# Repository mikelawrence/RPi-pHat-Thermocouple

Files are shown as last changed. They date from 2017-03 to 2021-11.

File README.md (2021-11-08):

# Raspberry Pi Thermocouple pHat

The Raspberry Pi Zero sized Hats are now officially called **Micro-Hats** or **uHats** but for consistency sake, this board's name will remain Raspberry Pi Thermocouple **pHat**.

This is a Raspberry Pi Micro-Hat PCB that supports:

* Three MAX31850 1-Wire Thermocouple Converters for remote temperature sensing
* DS18S20 1-Wire Thermometer for local Hat temperature
* Magnetic Buzzer/Alert

I keep an upright freezer in my garage and on two occasions I have had the freezer die without getting noticed for several days. This project is an attempt to solve my lack of constant oversight. MQTT is used to communicate with Home Assistant home automation software. The MQTT client/server model is very effective in this situation. Home Assistant will monitor the temperature and provide me with alerts so I can do something about the problem before all the food spoils.

## Status

* Rev 2.0 PCB has been ordered from OSH Park and has been fully tested.
  * Removed one of the four MAX31850K's.
  * Increased thermocouple input filtering by adding ferrite beads and a larger capacitor.
  * Added DC Power connector and switching power supply that powers both the Raspberry Pi and the Hat.
  * The occasional noisy reading from the MAX31850K's are reduced in this version but not gone.
  * You can order parts from Mouser using this [shared BOM](https://www.mouser.com/ProjectManager/ProjectDetail.aspx?AccessID=bd69c35967).
  * You can order the PCB from OSH Park using this [link](https://oshpark.com/shared_projects/meYar6Ji).
* Rev 1.2 PCB has been ordered from OSH Park and tested.
  * Discovered the MAX31850K's get a noisy reading about 0.1% of the time. This noise is typically within 5 C but sometimes is greater than 30 C. Adding capacitors did little to help the Rev 1.1 design so most of the 3.3V power was switched to a 3.3V LDO regulator in an attempt to reduce the noise on the 3.3V power seen by the MAX31850K's.
  * You can order parts from Mouser using this [shared BOM](http://www.mouser.com/ProjectManager/ProjectDetail.aspx?AccessID=7612d46eeb).
  * You can order the PCB from OSH Park using this [link](https://oshpark.com/shared_projects/S5a4ZDvw).
* Rev 1.1 PCB was never built.
  * Added a pulldown on the alert signal to prevent the Alert buzzer from sounding on power on.
  * Added an on board DS18S20.
* Rev 1.0 PCB has been ordered from OSH Park and tested.
  * Discovered the linux kernel doesn't seem to support MAX31850K devices without a DS18S20 present. The kernel detects the MAX31850K devices but does not create a w1_slave file to read the temperature. This is most likely a bug in the Linux W1 driver.

## Board Preview

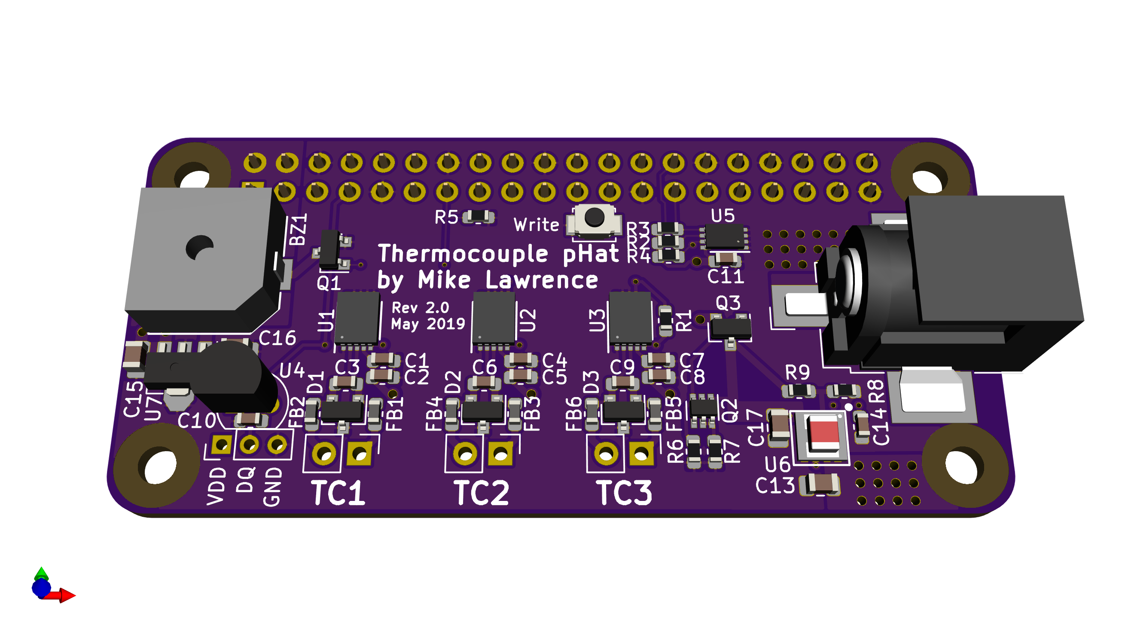
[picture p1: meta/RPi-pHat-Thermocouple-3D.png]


## Kicad Notes

* This PCB design uses my custom libraries available here [Mike's KiCad Libraries](https://github.com/mikelawrence/KiCad-Libraries).
* This PCB design is based on [RPi_Zero_pHat_Template](https://github.com/mikelawrence/RPi_Zero_pHat_Template).
* This PCB was designed with [KiCad 5.1.2](http://kicad.org).
* For Bill of Materials generation I use my version of [KiBoM](https://github.com/mikelawrence/KiBoM) forked from [SchrodingersGat](https://github.com/SchrodingersGat/KiBoM).
* The LMZ21700 Simple Switcher, AT24CS32, and MAX31850K parts have an exposed pad on the bottom which requires either a reflow oven or hot air to solder properly.

## Design

### Input Power

This Hat will safely power the Raspberry Pi and this board up to 650mA. Keep in mind that 650mA is not enough for the minimum specified backpower of 1.3A. It is however enough to power (with room to spare) a Raspberry Pi Zero W with nothing else connected. The Barrel Jack will accept 6-11VAC or 6-17VDC. This input voltage is rectified and filtered and applied to a 5VDC Simpler Switcher module from Texas Instruments (LMZ21700). The output of this switcher is applied to the Raspberry Pi 5V through an ideal diode circuit which will prevent any problems when both the Hat and Raspberry Pi are powered simultaneously.

### MAX31850K Thermocouple-to-Digital Converter

Although the MAX38150K datasheet typical application circuit doesn't show the use of ferrite beads many designs seem to include them. That in combination with the larger than normal capacitor across the input will hopefully improve sampling errors even further.

## Raspberry Pi Setup

This setup makes several assumptions. First you are using Raspbian Buster. This software and instructions most likely work on other versions of Raspbian but they have not been tested. Second Python3 is the target programming environment. It is also assumed that you are using the standard `pi` user. Otherwise you will have to edit the commands by replacing `/home/pi` with your user's home directory. Install everything needed by executing the following commands.

```text
sudo apt update
sudo apt -y install git python3-rpi.gpio python3-w1thermsensor python3-paho-mqtt
```

### Get the repository from Github

Clone this repository from Github with the following commands.

```text
cd /home/pi
git clone https://github.com/mikelawrence/RPi-pHat-Thermocouple
```

### Configure ID EEPROM

Raspberry Pi Hats require an ID EEPROM with data that uniquely identifies every hat ever made. Build the EEPROM tools, and make the `eeprom_settings.eep` file.

```text
cd /home/pi/RPi-pHat-Thermocouple/eeprom/
make all
./eepmake eeprom_settings.txt eeprom_settings.eep
```

The next command writes the freshly generated and unique `eeprom_settings.eep` file to the EEPROM but you must push and hold the write switch on the hat before executing this command. By default the EEPROM on the hat is write protected. Pushing the write switch allows writes to occur while the switch is pushed.

```text
chmod 755 eepflash.sh
sudo ./eepflash.sh -w -f=eeprom_settings.eep -t=24c32
```

You will see the following if writing to the EEPROM was successful.

```text
This will attempt to talk to an EEPROM at i2c address 0x50. Make sure there is an EEPROM at this address.
This script comes with ABSOLUTELY no warranty. Continue only if you know what you are doing.
Do you wish to continue? (yes/no): yes
Writing...
0+1 records in
0+1 records out
117 bytes (117 B) copied, 2.31931 s, 0.1 kB/s
Done.
```

This is what you will see if there is a problem communicating with the EEPROM.

```text
This will attempt to talk to an EEPROM at i2c address 0x50. Make sure there is an EEPROM at this address.
This script comes with ABSOLUTELY no warranty. Continue only if you know what you are doing.
Do you wish to continue? (yes/no): yes
Writing...
dd: error writing ‘/sys/class/i2c-adapter/i2c-3/3-0050/eeprom’: Connection timed out
0+1 records in
0+0 records out
0 bytes (0 B) copied, 0.0539977 s, 0.0 kB/s
Error doing I/O operation.
```

If you successfully wrote the EEPROM there is nothing else left to do here.

### Setup Interfaces

For this Hat you will need to enable the 1-Wire interface. From the command line type
`sudo raspi-config` and follow the prompts to install  support in the kernel.

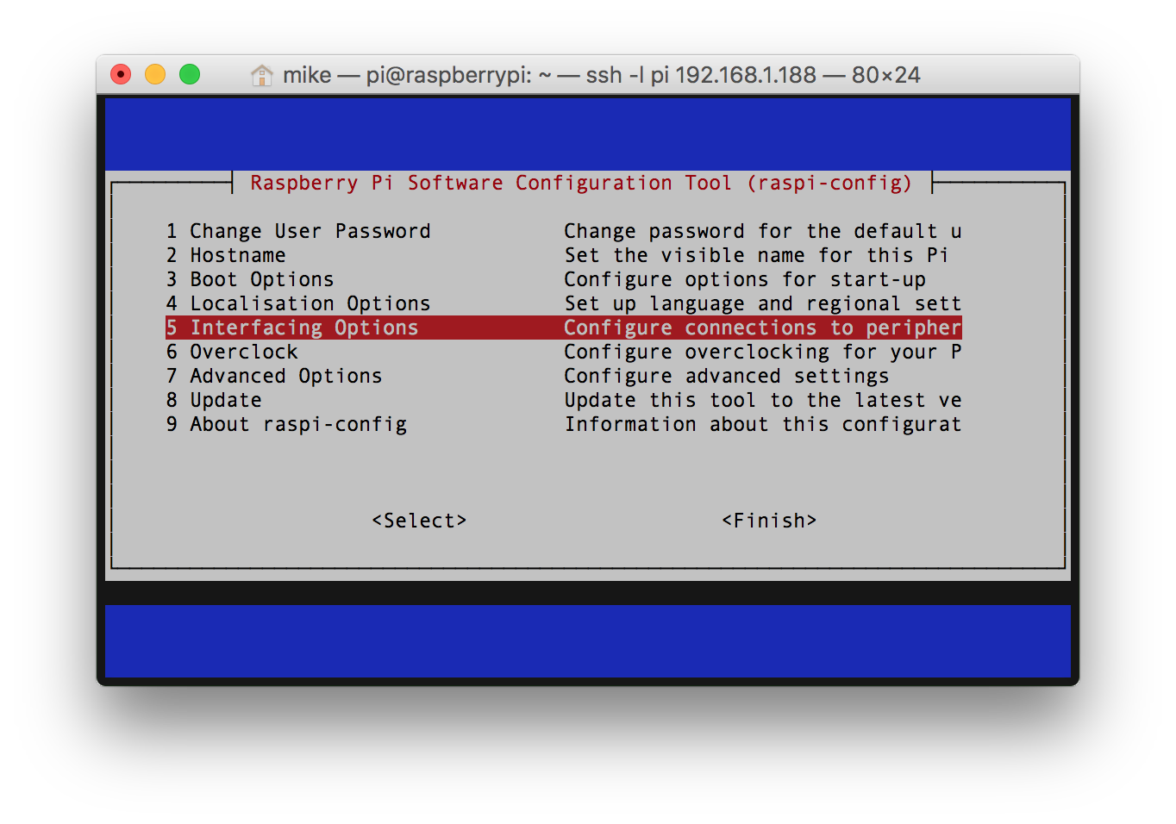
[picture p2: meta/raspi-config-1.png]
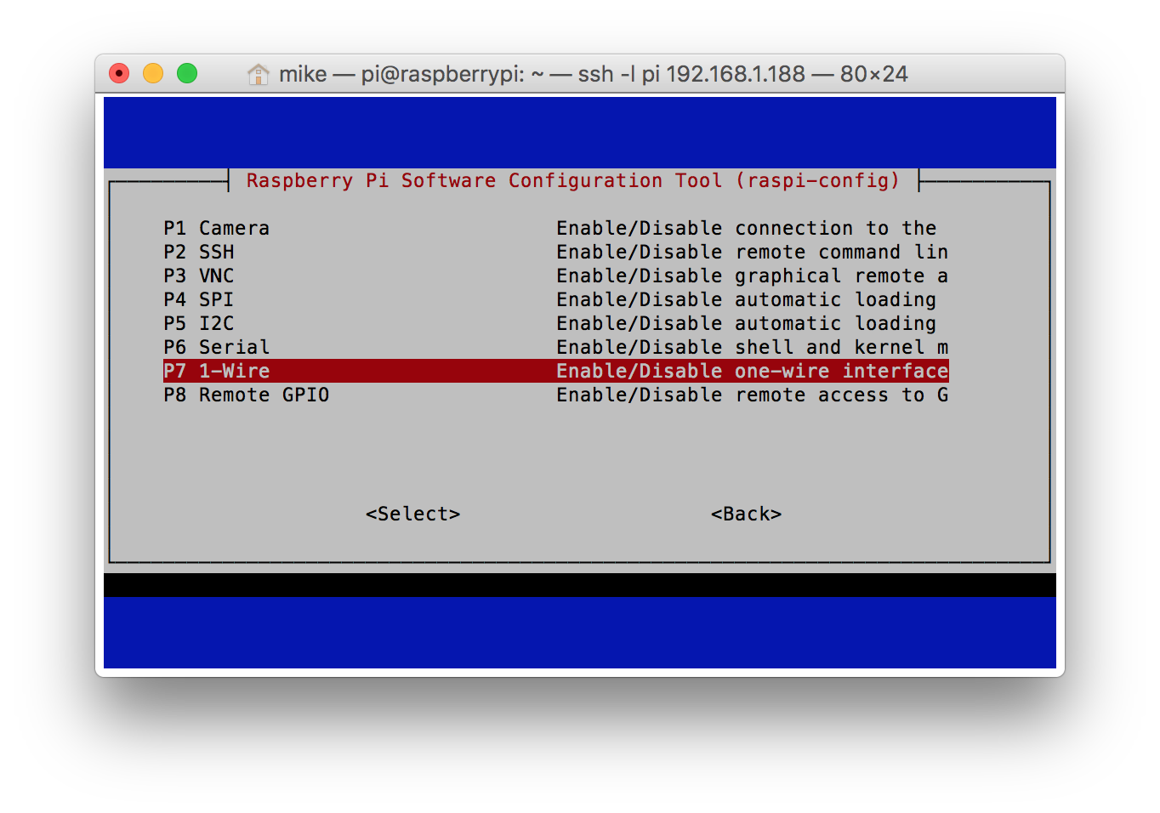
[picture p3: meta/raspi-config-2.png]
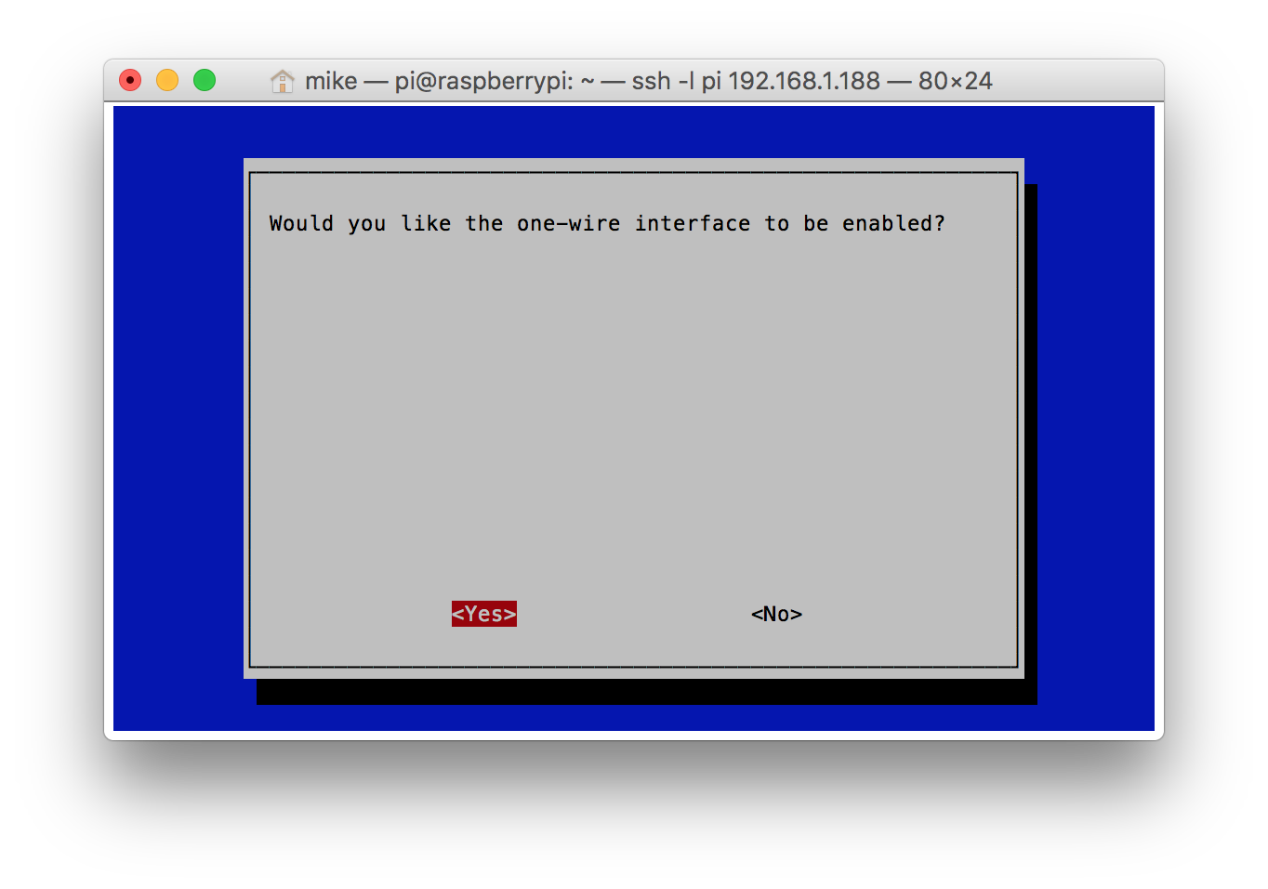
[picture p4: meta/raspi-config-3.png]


It's time to reboot your Raspberry Pi with `sudo reboot`.

### Test the 1-Wire Temperature Sensors

[Python3-w1thermsensor](https://github.com/timofurrer/w1thermsensor) is a nice 1-Wire python library that also supports command line reading of temperatures from 1-Wire devices. You should have already installed this package in the [Raspberry Pi Setup](#Raspberry-Pi-Setup) section.

Test the single on-board DS18B20 temperature sensor using `w1thermsensor all --type DS18S20`.

```text
pi@studio-fridge:~ $ w1thermsensor all --type DS18S20
Got temperatures of 1 sensors:
  Sensor 1 (00080372f2c4) measured temperature: 28.06 celsius
```

Now test the three MAX38150Ks temperature sensor by using `w1thermsensor all --type MAX31850K`.

```text
pi@studio-fridge:~ $ w1thermsensor all --type MAX31850K
Got temperatures of 3 sensors:
  Sensor 1 (000000181928) measured temperature: 23.75 celsius
  Sensor 2 (00000018192b) measured temperature: 24.0 celsius
  Sensor 3 (000000181d59) measured temperature: 2047.81 celsius
```

The 2047.81 celsius reading is what you get when there is no thermocouple connected to the MAX31850K.

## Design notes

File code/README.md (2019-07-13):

# Fridge Monitor Application

The Fridge Monitor application is written in Python 3 and supports the hardware elements of the Raspberry Pi Zero Thermocouple pHat which can measure up to 3 thermocouple temperatures. The main function is to monitor the temperatures inside a refridgerator/freezer. These temperatures are reported at a configurable rate. If the temperatures rise above a configurable set point the application will set an alarm. The application is discoverable by [Home Assistant](https://home-assistant.io/), an open-source home automation platform also running Python 3. [MQTT](http://mqtt.org/), a machine-to-machine (M2M)/"Internet of Things" connectivity protocol, is the basis of communication with Home Assistant.

## Configuration Notes

All settings for this application are in the '[fridgemonitor.conf](fridgemonitor.conf)'. This is where you point to the correct MQTT broker and configure how the temperature sensors work. There are a few settings of note here. Discovery_Enabled = false will prevent Home Assistant from automatically discovering the Fridge Monitor.

## Home Assistant Notes

When Discovery is enabled Home Assistant will automatically pick up the Alarm Disable switch, Alarm binary_sensor, RSSI sensor, four temperature sensors, and three door sensors. The is a DS18S20 1-Wire Thermometer on the board and three thermocouple inputs for measuring temperature remotely with thermocouple wire.

If you don't want to use discovery here is the configuration of the Fridge Monitor in Home Assistant. Note the 'studio_fridge_monitor' you see in the example yaml is the Node_ID which is specified in the 'fridgemonitor.conf' file.

```yaml
switch:
  - platform: mqtt
    sensors:
      # This switch provides a means to turn off both the audible alert and alarm boolean_sensor
      #   This switch will automatically turn back OFF at 6PM every day.
      name: "Studio Fridge Monitor Alert Disable"
        state_topic: "homeassistant/switch/studio_fridge_monitor/alert_disable/state"
        command_topic: "homeassistant/switch/studio_fridge_monitor/alert_disable/set"
        availability_topic: "homeassistant/switch/studio_fridge_monitor/avail"
        qos: 1
# The following sensors are updated at Sensor_Publish_Rate specified in the frigdemonitor.conf file
sensor:
  - platform: mqtt
    sensors:
      # WiFi Received Signal Strength Indicator (RSSI)
      name: "Studio Fridge Monitor RSSI"
        state_topic: "homeassistant/sensor/studio_fridge_monitor/rssi/state"
        availability_topic: "homeassistant/switch/studio_fridge_monitor/avail"
        unit_of_measurement: 'dBm'
      # Temperature measured by the DS18S20 Sensor (1 minute average)
      name: "Studio Fridge Monitor Temperature"
        state_topic: "homeassistant/sensor/studio_fridge_monitor/temperature/state"
        availability_topic: "homeassistant/switch/studio_fridge_monitor/avail"
        unit_of_measurement: '°C'
      # Temperature measured by the MAX31850K Thermocouple Sensor (TC1) (1 minute average)
      name: "Studio Fridge Temperature"
        state_topic: "homeassistant/sensor/studio_fridge_monitor/TC1_temperature/state"
        availability_topic: "homeassistant/switch/studio_fridge_monitor/avail"
        unit_of_measurement: '°C'
      # Temperature measured by the MAX31850K Thermocouple Sensor (TC2) (1 minute average)
      # if TC_Count in configuration file is set to 1 then this sensor does not exist
      name: "Studio Freezer Temperature"
        state_topic: "homeassistant/sensor/studio_fridge_monitor/TC2_temperature/state"
        availability_topic: "homeassistant/switch/studio_fridge_monitor/avail"
        unit_of_measurement: '°C'
      # Temperature measured by the MAX31850K Thermocouple Sensor (TC3) (1 minute average)
      # if TC_Count in configuration file is set to 2 or 1 then this sensor does not exist
      name: "Studio Fridge Compressor Temperature"
        state_topic: "homeassistant/sensor/studio_fridge_monitor/TC3_temperature/state"
        availability_topic: "homeassistant/switch/studio_fridge_monitor/avail"
        unit_of_measurement: '°C'
      # Temperature measured by the MAX31850K Thermocouple Sensor (TC1) (24 hour average)
      name: "Studio Fridge Average"
        state_topic: "homeassistant/sensor/studio_fridge_monitor/TC1_average/state"
        availability_topic: "homeassistant/switch/studio_fridge_monitor/avail"
        unit_of_measurement: '°C/min'
      # Temperature measured by the MAX31850K Thermocouple Sensor (TC2) (24 hour average)
      # if TC_Count in configuration file is set to 1 then this sensor does not exist
      name: "Studio Freezer Average"
        state_topic: "homeassistant/sensor/studio_fridge_monitor/TC2_average/state"
        availability_topic: "homeassistant/switch/studio_fridge_monitor/avail"
        unit_of_measurement: '°C/min'
      # Temperature measured by the MAX31850K Thermocouple Sensor (TC3) (24 hour average)
      # if TC_Count in configuration file is set to 2 or 1 then this sensor does not exist
      name: "Studio Fridge Compressor Average"
        state_topic: "homeassistant/sensor/studio_fridge_monitor/TC3_average/state"
        availability_topic: "homeassistant/switch/studio_fridge_monitor/avail"
        unit_of_measurement: '°C/min'
binary_sensor:
  - platform: mqtt
    sensors:
      # When active the Fridge Monitor has detected an over temperature condition
      #   on any thermocouple sensor
      name: "Studio Fridge Monitor Alarm"
        state_topic: "homeassistant/binary_sensor/studio_fridge_monitor/alarm/state"
        availability_topic: "homeassistant/switch/studio_fridge_monitor/status"
        device_class: "heat"
      # Analysis of TC1 to determine if the door is open
      name: "Studio Fridge Door"
        state_topic: "homeassistant/sensor/studio_fridge_monitor/TC1_door/state"
        availability_topic: "homeassistant/switch/studio_fridge_monitor/avail"
        device_class: "door"
      # Analysis of TC2 to determine if the door is open
      # if TC_Count in configuration file is set to 1 then this sensor does not exist
      name: "Studio Freezer Door"
        state_topic: "homeassistant/sensor/studio_fridge_monitor/TC2_door/state"
        availability_topic: "homeassistant/switch/studio_fridge_monitor/avail"
        device_class: "door"
      # Analysis of TC3 to determine if the door is open
      #  this doesn't make sense for compressor temperature monitor
      # if TC_Count in configuration file is set to 2 or 1 then this sensor does not exist
      name: "Studio Fridge Compressor Door"
        state_topic: "homeassistant/sensor/studio_fridge_monitor/TC3_door/state"
        availability_topic: "homeassistant/switch/studio_fridge_monitor/avail"
        device_class: "door"
```

## Raspberry Pi Setup

It is assumed that you already followed the instructions in the Raspberry Pi Setup section of the main project [README file](../README.md). If you have not, please do so now before continuing. Be sure to edit the 'fridgemonitor.conf' file to support your configuration. Test the software by executing the following commands. Note if you are not using the standard `pi` user you will have to edit the commands by replacing `/home/pi` with your user's home directory.

```text
cd /home/pi/RPi-pHat-Thermocouple/code/
chmod 755 fridgemonitor.py
./fridgemonitor.py
```

If you see no errors you should be able to see one switch, one binary_sensor, and four sensors in Home Assistant. Configuring Home Assistant is a bit of a stretch for this guide but here are a couple of hints.

* "Fridge Monitor: Failed to load state file 'fridgemonitor.json'." means there is no previous state for the light. This is perfectly normal when the code is run for the first time.
* Make sure you have MQTT installed. If you use HASS.IO goto the HASS.IO configuration and install the Mosquitto Broker.
* Make sure you have MQTT discovery enabled. See [MQTT Discovery](https://home-assistant.io/docs/mqtt/discovery/).
* Make sure your MQTT discovery prefix matches the Discovery_Prefix in your Fridge Monitor configuration file.

Installing a MQTT server is easy if you are running Hass.io, just look for the Mosquitto Broker in the Add_On Store.

## Systemd run at boot

If you are not using the standard `pi` user you will also have to edit the `fridgemonitor.service` file so that links point to the correct directory.

Execute the following commands to install Fridge Monitor as a systemd service to run on startup.

```text
cd /home/pi/RPi-pHat-Thermocouple/code
sudo cp fridgemonitor.service /lib/systemd/system
sudo chmod 644 /lib/systemd/system/fridgemonitor.service
sudo systemctl enable fridgemonitor.service
sudo systemctl start fridgemonitor.service
```

## Notes

* The Raspberry Pi should be placed on the outside of the refridgerator/freezer and thermocouple wire should be run inside to measure the temperatures.

* The pHat seems to have some infrequent noise in the readings. Thermocouples are also good at picking up noise so the software trys to eliminate noisy readings. If a thermocouple reading is greater than ±3°C away from last reading the sample will be thrown out. It will do this up to 3 times in a row before allowing the 4th out of bounds sample to pass through.  

* All temperature sensors are sampled every 5 seconds. These samples are averaged every minute. These 1 minute averages are keep for 24 hours to compute an 24 hour average. The 1 minute samples are saved to disk so power interruption or reboot will prevent the complete loss of data for the 24 hour average.

* The door sensors use how fast temperature rises on the 1 minute averages to detect when a door is open. This is reasonable for normal operation but there are problems with this approach. For instance, a quick open and close might be missed especially if the compressor is on and the temperature is falling. If the door is left open eventually the rise in temperature will level out and the door will be recognized as closed.

## Acknowledgments

The following python libraries are required.

* [Eclipse Paho™ MQTT Python Client](https://github.com/eclipse/paho.mqtt.python)
* [Python3 w1thermsensor](https://github.com/timofurrer/w1thermsensor)
* [Adafruit Python GPIO](https://github.com/adafruit/Adafruit_Python_GPIO)

The following code came from Github

* [W1ThermSensor](https://github.com/timofurrer/w1thermsensor/blob/master/w1thermsensor/core.py)

The following code was pulled from the Internet

* [timer.py](https://github.com/jalmeroth/homie-python/blob/master/homie/timer.py)

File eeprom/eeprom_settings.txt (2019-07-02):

########################################################################
# EEPROM settings text file
#
# This text file has been modifed for the
#  Raspberry Pi Thermocouple pHat Rev 2.0
#
########################################################################

########################################################################
# Vendor info

# 128 bit UUID. If left at zero eepmake tool will auto-generate
# RFC 4122 compliant UUID
product_uuid 00000000-0000-0000-0000-000000000000

# 16 bit product id
product_id 0x0002

# 16 bit product version
product_ver 0x0200

# ASCII vendor string  (max 255 characters)
vendor "Mike Lawrence"

# ASCII product string (max 255 characters)
product "Raspberry Pi Thermocouple pHat"

########################################################################
# GPIO bank settings, set to nonzero to change from the default.
# NOTE these setting can only be set per BANK, uncommenting any of
# these will force the bank to use the custom setting.

# drive strength, 0=default, 1-8=2,4,6,8,10,12,14,16mA, 9-15=reserved
gpio_drive 0

# 0=default, 1=slew rate limiting, 2=no slew limiting, 3=reserved
gpio_slew 0

# 0=default, 1=hysteresis disabled, 2=hysteresis enabled, 3=reserved
gpio_hysteresis 0

# If board back-powers Pi via 5V GPIO header pins:
# 0 = board does not back-power
# 1 = board back-powers and can supply the Pi with a minimum of 1.3A
# 2 = board back-powers and can supply the Pi with a minimum of 2A
# 3 = reserved
# If back_power=2 then USB high current mode will be automatically
# enabled on the Pi
back_power 0

########################################################################
# GPIO pins, uncomment for GPIOs used on board
# Options for FUNCTION: INPUT, OUTPUT, ALT0-ALT5
# Options for PULL: DEFAULT, UP, DOWN, NONE
# NB GPIO0 and GPIO1 are reserved for ID EEPROM so cannot be set

#         GPIO  FUNCTION  PULL
#         ----  --------  ----
#setgpio  2     INPUT     DEFAULT
#setgpio  3     INPUT     DEFAULT
#setgpio  4     INPUT     DEFAULT
#setgpio  5     INPUT     DEFAULT
#setgpio  6     INPUT     DEFAULT
#setgpio  7     INPUT     DEFAULT
#setgpio  8     INPUT     DEFAULT
#setgpio  9     INPUT     DEFAULT
#setgpio  10    INPUT     DEFAULT
#setgpio  11    INPUT     DEFAULT
#setgpio  12    INPUT     DEFAULT
#setgpio  13    INPUT     DEFAULT
#setgpio  14    INPUT     DEFAULT
#setgpio  15    INPUT     DEFAULT
#setgpio  16    INPUT     DEFAULT
#setgpio  17    INPUT     DEFAULT
#setgpio  18    INPUT     DEFAULT
#setgpio  19    INPUT     DEFAULT
#setgpio  20    INPUT     DEFAULT
#setgpio  21    INPUT     DEFAULT
#setgpio  22    INPUT     DEFAULT
#setgpio  23    INPUT     DEFAULT
#setgpio  24    INPUT     DEFAULT
#setgpio  25    INPUT     DEFAULT
#setgpio  26    INPUT     DEFAULT
#setgpio  27    OUTPUT    NONE

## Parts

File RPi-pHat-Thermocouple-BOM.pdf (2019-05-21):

Quantity | References | Description | Manufacturer | Part Number | Vendor | Vendor Part Number
1 | BZ1 | BUZ, SMD, 2.7kHz, 5V, 30mA | CUI | CMI-9655S-SMT-TR | Mouser | 490-CMI-9655S-SMT-TR
8 | C1 C3 C4 C6 C7 C9 C10 C11 | CAP, 0603, .1uF, 10%, X7R, 50V | Yageo | CC0603KRX7R9BB104 | Mouser | 603-CC603KRX7R9BB104
3 | C2 C5 C8 | CAP, 0603, .01uF, 10%, X7R, 50V | Murata Electronics | CC0603KRX7R9BB103 | Mouser | 603-CC603KRX7R9BB103
1 | C12 | CAP, SMD10X8, 330uF, 20%, EC, 20V | Nichicon | PCR1D331MCL1GS | Mouser | 647-PCR1D331MCL1GS
2 | C13 C17 | CAP, 0805, 22uf, 20%, X5R, 25V | Taiyo Yuden | TMK212BBJ226MG-TT | Mouser | 963-TMK212BBJ226MGTT
1 | C14 | CAP, 0603, 3300pF, 5%, X7R, 10V | Vishay | VJ0603Y332JXQPW1BC | Mouser | 77-VJ0603Y332JXQPBC
2 | C15 C16 | CAP, 0805, 2.2uF, 10%, X7R, 16V | Yageo | CC0805KKX7R7BB225 | Mouser | 603-CC805KKX7R7BB225
3 | D1 D2 D3 | TVS, SOT23, ESD TVS Protection | On Semi | NUP2105LT1G | Mouser | 863-NUP2105LT1G
1 | D4 | DIODE, DFS, Bridge Diode, 2A, 600V | Comchip | DF206ST-G | Mouser | 750-DF206ST-G
6 | FB1 FB2 FB3 FB4 FB5 FB6 | BEAD, 0603, .3A, 1k@100MHz | TDK | MMZ1608B102CTD25 | Mouser | 810-MMZ1608B102CTD25
1 | J1 | CON, THT, Dual Row Socket, 2.54mm, 40 Pos | Adafruit | 2222 | Mouser | 485-2222
1 | J2 | CON, SMD, Barrel Jack, 2.0mm center | CUI | PJ-036AH-SMT-TR | Mouser | 490-PJ-036AH-SMT-TR
1 | Q1 | IC, SOT23, Inductive Load Driver | On Semi | NUD3124LT1G | Mouser | 863-NUD3124LT1G
1 | Q2 | TRANSISTOR, SOT363, Bipolar, PNP, Dual Matched | Diodes Inc | BCM857BS-7-F | Mouser | 621-BCM857BS-7-F
1 | Q3 | TRANSISTOR, SOT23, Mosfet, P-CH, -5A, -20V | Diodes Inc | DMG2305UX-7 | Mouser | 621-DMG2305UX-7
2 | R1 R5 | RES, 0603, 4.7k, 1%, T100 | Panasonic | ERJ-3EKF4701V | Mouser | 667-ERJ-3EKF4701V
2 | R2 R3 | RES, 0603, 3.9k, 1%, T100 | Panasonic | ERJ-3EKF3901V | Mouser | 667-ERJ-3EKF3901V
1 | R4 | RES, 0603, 1k, 1%, T100 | Panasonic | ERJ-3EKF1001V | Mouser | 667-ERJ-3EKF1001V
1 | R6 | RES, 0603, 47k, 1%, T100 | Panasonic | ERJ-3EKF4702V | Mouser | 667-ERJ-3EKF4702V
1 | R7 | RES, 0603, 10k, 1%, T100 | Panasonic | ERJ-3EKF1002V | Mouser | 667-ERJ-3EKF1002V
1 | R8 | RES, 0603, 44.2k, 1%, T100 | Panasonic | ERJ-3EKF4422V | Mouser | 667-ERJ-3EKF4422V
1 | R9 | RES, 0603, 232k, 1%, T100 | Yageo | RC0603FR-07232KL | Mouser | 603-RC0603FR-07232KL
1 | SW1 | SW, SMD, Push Button | Omron | B3U-1000P | Mouser | 653-B3U-1000P
3 | U1 U2 U3 | IC, TDFN10, 1-Wire Thermocouple Converter | Maxim | MAX31850KATB+ | Mouser | 700-MAX31850KATB+
1 | U4 | IC, TO92, 1-Wire Temperature Sensor | Maxim | DS18S20+ | Mouser | 700-DS18S20
1 | U5 | IC, DFN8, I2C Serial EEPROM, 32kbit | Atmel | AT24CS32-MAHM-E | Mouser | 556-AT24CS32-MAHM-E
1 | U6 | MODULE, SMD, Simple Switcher, 17V, .65A | TI | LMZ21700SILR | Mouser | 595-LMZ21700SILR
1 | U7 | IC, SOT89-3, LDO VREG, 16V, .15A | Microchip | MCP1754ST-3302E/MB | Mouser | 579-MCP1754ST3302EMB

# RPi pHat Thermocouple BOM Rev 2.0

1

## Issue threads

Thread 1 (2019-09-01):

what sort of connectors for thermocouple cables?

lmamakos, 2019-09-01:
I'm wondering what you're using to connect the thermocouple wires to the PCB?  The space looks pretty right given the components on the top side of the board.  Do you have some terminal block arrangement in mind?  Or are these intended for 2.54mm pitch pin headers, with some sort of connector body and pins on the end of the thermocouple cable?  If you're using some solution that you're happy with, I'd love to avoid inventing my own flat-tire solution.

I'm planning to replicate your project as I have need for some thermocouple sensors.  I'm planning to integrate it with my RPi Zero inside my Generac generator to measure various temperatures, including oil temperature at the air cooler, probably the body of the generator, motor and/or air exhaust from the enclosure of the air-cooled engine.

(FYI, planning to use this in concert with genmon https://github.com/jgyates/genmon that I've had in service for about a year now..)

mikelawrence, 2019-09-02:
Given how little space there is on the Raspberry Pi Zero Hat I chose to solder the thermocouple wires directly to the PCB. This can be a bit fiddly since thermocouple wire is not that compatible with standard solder but it can be done. You can also apply a bit of rigid RTV to help with strain relief.
Looking at your application I think you should consider extending the PCB so you can add some standard 0.1" screw terminal blocks. I've done this in the past with success also.

lmamakos, 2019-09-02:
Thanks for the suggestion.  I've ordered the board as-is from OSH Park and will probably built it as-is initially.  Maybe solder on some right-angle pin headers and crimp some corresponding female connector pins on the thermocouple wires.

I was toying with the idea of doing a board to also include an RS-232/TTL level converter, which have dangling separately at the moment.  Perhaps make it optoisolated while I'm at it.  I should have the room to do so, though a combination of making the board larger and/or leaving out the buzzer and little switching power supply component (which I'm not looking forward to soldering with my hot-air tool!)  This will give me a reason to switch over and learn KiCAD from Eagle that I've used before to spin a board.

mikelawrence, 2019-09-02:
The header/pin approach should work fine. The main thing is to keep the thermal resistance low between the MAX38150 and the cold junction.

KiCAD has improved by leaps and bounds in the last few years. I come from a PADS background and found KiCAD easy to use where Eagle just made me mad. With the support of CERN and being open source I think KiCAD will come to dominate the hobbyist PCB sector.

If that little switching power supply is too much you can leave it off and just power the board through the Raspberry Pi's USB port.

lmamakos, 2019-09-02:
I was playing around a little bit with KiCad, and just moving the pads closer to the board edge where the silkscreen labels _might just_ work, though I might enlarge the board a bit anyway.

I'm looking forward to learning KiCAD a bit; going to watch some of the videos over time time off next week to avoid learning it all the hard way.  Eagle.. sure seems to be fairly complete, though I don't use it more than once ever few years (if that much), so there's no muscle memory.  It also seems to be the wrong bet to place these days, and a buddy of mine has been using KiCAD for a few years for his hobby projects, so I have someone to help me get unstuck.

I'm going to give the switching power supply a shot; I ordered some Sn63/Pb37  chip quik solder paste from Mouser to see if I can successfully solder it.  I don't have any reflow oven capability, so just the hot-air tool and I figure that I need to maybe pre-heat the back of the board a little bit to get everything to flow before knocking that inductor loose on top.

Still, it would be handy to have the power supply working.  I have an external 12v/5v USB power supply that connects to the 12V battery in the generator to run the Pi Zero (and a USB WiFi dongle that has an external antenna I mount on the outside of the metal generator enclosure).  Getting rid of another loose end like that would clean things up a bit.

Thanks for the extra effort you undertook to publish and update this project; it's really appreciated.

If I do end up modifying the board and spinning my own version, I'll also publish it.  I think there may be some other people in the "genmon" community that would be interested in replicating the solution, especially if I also included an RS-232 / TTL adapter that's used to connect the MODBUS interface on the generator to the Raspberry Pi serial port.  I think having it be optically isolated would also help with some occasional problems that people have with ground loops.

mikelawrence, 2019-09-02:
Good luck with the hot air. I've been using a Black and Decker oven with a [Whizoo Controller](https://whizoo.com/) for the last few years. It makes all the surface mount stuff a no-brainer and it's why my designs are not that friendly to hand soldering.

You may already know this but the Raspberry Pi Zero W has a place to solder a [u.FL connector](https://www.briandorey.com/post/raspberry-pi-zero-w-external-antenna-mod) so you can attach an external antenna to the onboard wireless controller. I have a friend that did this for his beehive monitor.

You are welcome! I love the idea of somebody else picking up one of my designs and modifying it for their needs and if you publish your mods that's a great way to pay it forward!

lmamakos, 2019-09-03:
Oh, thanks for the pointer about the u.FL connector!  That would simplify matters quite a bit and make the little project box much less crowded.  Probably for rev.2 if I spin my own board, I'll just get another Pi Zero and do the mod to it.

lmamakos, 2020-05-07:
I forked your design, and did a major revision adding screw terminals and an RS-232 interface for a specific standby generator application.  It's also back to being a full-size Raspberry Pi board.  See https://github.com/lmamakos/RPi-pHat-Thermocouple if you'd like.  I have credited you in the README, hopefully that's OK with you.  If you're prefer me to not mention you explicitly to completely shield you from any blame, I can do that to.  Thanks very much for sharing your design.

After spinning two versions of the board and building them by hand with a hot air tool, and I'm slowing talking myself into a reflow oven..    Preheating on a hot-plate thing to 165C to soak the board and components before hitting them with the hot air tool seems to work pretty good, so long as you remember to hit all of the parts.

mikelawrence, 2020-05-07:
I think the whole point of putting projects like mine on Github is so people like you can fork it make it your own just like you did. From my point of view just a simple mention that your project is based on mine with a link is nice but event that is not required. Now that your work is also on Github somebody else can be inspired by your design and hopefully is keeps getting paid forward.

I like that transformer based digital isolator you used for the RS-232.

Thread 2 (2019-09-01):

OSHPark link to the rev 2 board is wrong in README.md

lmamakos, 2019-09-01:
Still points to the rev 1.2 board..

mikelawrence, 2019-09-02:
Issue is now fixed.

Closed 2019-09-02.

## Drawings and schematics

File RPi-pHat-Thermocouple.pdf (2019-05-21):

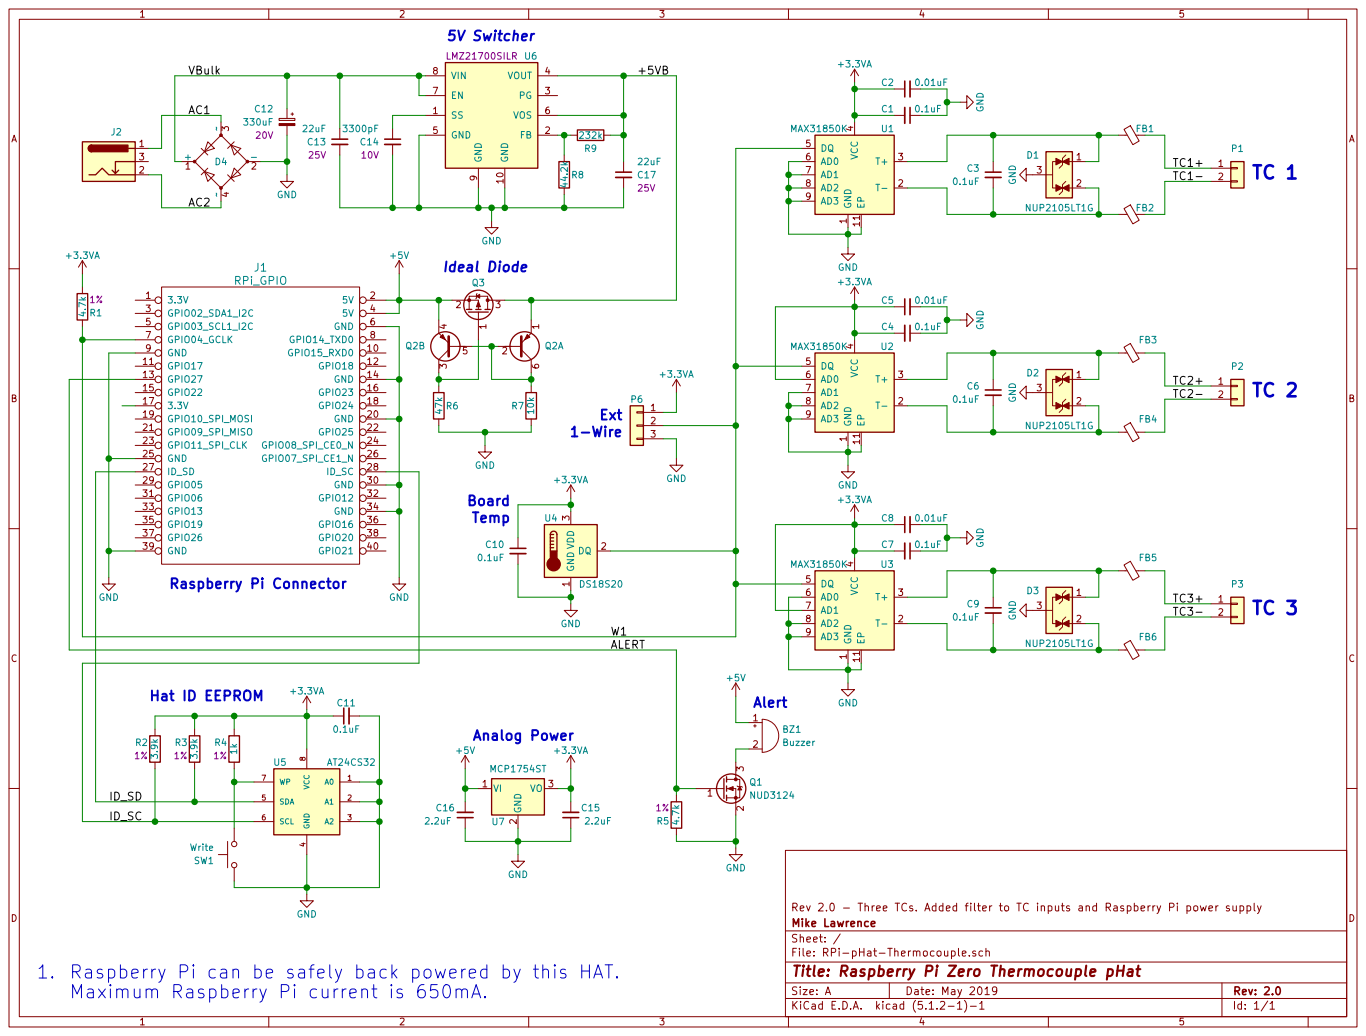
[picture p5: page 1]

3 4 D4 5V Switcher SS 1 GND 10 FB 2 PG 3 VOUT 4 GND 5 VOS 6 EN 7 VIN 8 GND

4 SDA 5 SCL 6 WP 7 VCC

File: RPi-pHat-Thermocouple.sch Sheet: / Mike Lawrence Rev 2.0 - Three TCs. Added filter to TC inputs and Raspberry Pi power supply

Id: 1/1 Title: Raspberry Pi Zero Thermocouple pHat

Maximum Raspberry Pi current is 650mA.

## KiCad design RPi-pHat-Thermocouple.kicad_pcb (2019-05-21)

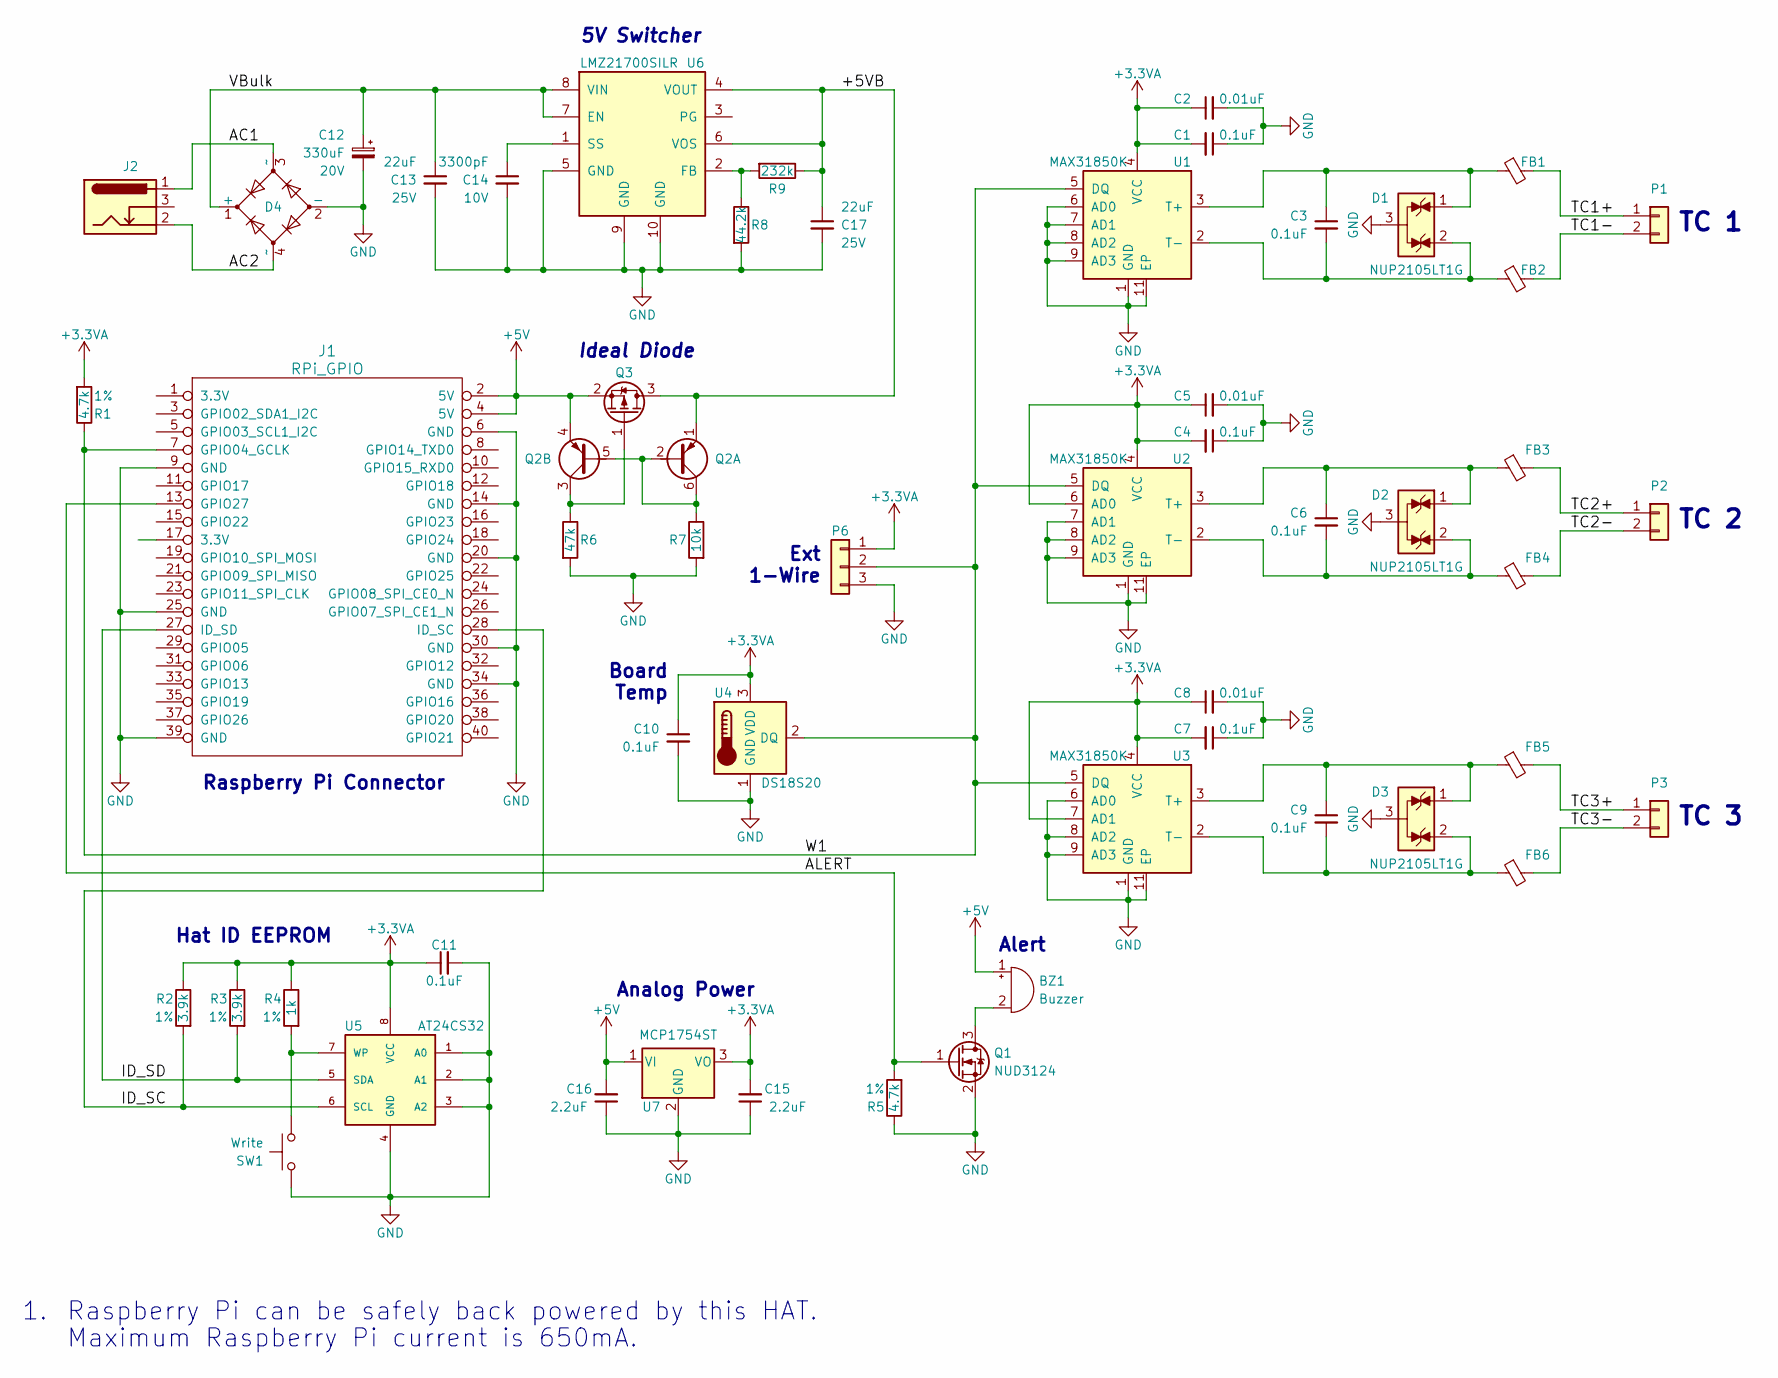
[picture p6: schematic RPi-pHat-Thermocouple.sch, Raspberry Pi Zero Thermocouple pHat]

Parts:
BZ1: Buzzer; MagneticBuzzer_CUI-CMI-9655S; Part Number CMI-9655S-SMT-TR
C1, C3, C4, C6, C7, C9, C10, C11: 0.1uF; C_0603_1608Metric; Part Number CC0603KRX7R9BB104
C2, C5, C8: 0.01uF; C_0603_1608Metric; Part Number CC0603KRX7R9BB103
C12: 330uF; CP_Elec_10x7.9; Voltage 20V; Tolerance 20%; Part Number PCR1D331MCL1GS
C13, C17: 22uF; C_0805_2012Metric; Voltage 25V; Tolerance 20%; Part Number TMK212BBJ226MG-TT
C14: 3300pF; C_0603_1608Metric; Voltage 10V; Tolerance 5%; Part Number VJ0603Y332JXQPW1BC
C15, C16: 2.2uF; C_0805_2012Metric; Part Number CC0805KKX7R7BB225
D1, D2, D3: NUP2105LT1G; SOT-23; Part Number NUP2105LT1G
D4: Diode_Bridge_Vishay_DFS; Part Number DF206ST-G
FB1, FB2, FB3, FB4, FB5, FB6: 1k; L_0603_1608Metric; Part Number MMZ1608B102CTD25
J1: RPi_GPIO; PinSocket_2x20_P2.54mm_Vertical; Part Number 2222
J2: Barrel_Jack_Switch; BarrelJack_CUI_PJ-036AH-SMT_Horizontal; Part Number PJ-036AH-SMT-TR
P1, P2, P3: CONN_01X02; Pin_Header_Straight_1x02_Pitch2.54mm
P6: CONN_01X03; Pin_Header_Straight_1x03_Pitch2.00mm
Q1: NUD3124; SOT-23; Part Number NUD3124LT1G
Q2: BCM857BS; SOT-363_SC-70-6; Part Number BCM857BS-7-F
Q3: DMG2305UX; SOT-23; Part Number DMG2305UX-7
R1, R5: 4.7k; R_0603_1608Metric; Tolerance 1%; Part Number ERJ-3EKF4701V
R2, R3: 3.9k; R_0603_1608Metric; Tolerance 1%; Part Number ERJ-3EKF3901V
R4: 1k; R_0603_1608Metric; Tolerance 1%; Part Number ERJ-3EKF1001V
R6: 47k; R_0603_1608Metric; Tolerance 1%; Part Number ERJ-3EKF4702V
R7: 10k; R_0603_1608Metric; Tolerance 1%; Part Number ERJ-3EKF1002V
R8: 44.2k; R_0603_1608Metric; Tolerance 1%; Part Number ERJ-3EKF4422V
R9: 232k; R_0603_1608Metric; Tolerance 1%; Part Number RC0603FR-07232KL
SW1: Write; SW_SPST_B3U-1000P; Part Number B3U-1000P
U1, U2, U3: MAX31850K; TDFN-10-1EP_3x4mm_Pitch0.5mm; Part Number MAX31850KATB+
U4: DS18S20; TO-92; Part Number DS18S20+
U5: AT24CS32; DFN-8-1EP_3x2mm_P0.5mm_EP1.3x1.5mm; Part Number AT24CS32-MAHM-E
U6: LMZ21700; Converter_DCDC_Texas-SIL0008E; Part Number LMZ21700SILR
U7: MCP1754ST; SOT-89-3; Part Number MCP1754ST-3302E/MB

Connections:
+3.3VA: C1.2, C2.1, C4.2, C5.1, C7.2, C8.1, C10.1, C11.1, C15.2, P6.1, R1.2, R2.1, R3.1, R4.1, U1.4 (VCC), U2.4 (VCC), U2.6 (AD0), U3.4 (VCC), U3.7 (AD1), U4.3 (VDD), U5.8 (VCC), U7.3 (VO)
+5V: BZ1.1 (-), C16.2, J1.2 (5V), J1.4 (5V), Q2.4 (E2), Q3.2 (S), U7.1 (VI)
/+5VB: C17.1, Q2.1 (E1), Q3.3 (D), R9.1, U6.4 (VOUT), U6.6 (VOS)
/AC1: D4.3 (~~), J2.1
/AC2: D4.4 (~~), J2.2
/ALERT: J1.13 (GPIO27), Q1.1 (G), R5.2
/ID_SC: J1.28 (ID_SC), R2.2, U5.6 (SCL)
/ID_SD: J1.27 (ID_SD), R3.2, U5.5 (SDA)
/TC1+: FB1.2, P1.1
/TC1-: FB2.2, P1.2
/TC2+: FB3.2, P2.1
/TC2-: FB4.2, P2.2
/TC3+: FB5.2, P3.1
/TC3-: FB6.2, P3.2
/VBulk: C12.1, C13.1, D4.1 (+), U6.7 (EN), U6.8 (VIN)
/W1: J1.7 (GPIO04_GCLK), P6.2, R1.1, U1.5 (DQ), U2.5 (DQ), U3.5 (DQ), U4.2 (DQ)
GND: C1.1, C2.2, C4.1, C5.2, C7.1, C8.2, C10.2, C11.2, C12.2, C13.2, C14.2, C15.1, C16.1, C17.2, D1.3 (A), D2.3 (A), D3.3 (A), D4.2 (-), J1.6 (GND), J1.9 (GND), J1.14 (GND), J1.20 (GND), J1.25 (GND), J1.30 (GND), J1.34 (GND), J1.39 (GND), P6.3, Q1.2 (S), R5.1, R6.2, R7.2, R8.2, SW1.1, U1.1 (GND), U1.6 (AD0), U1.7 (AD1), U1.8 (AD2), U1.9 (AD3), U1.11 (EP), U2.1 (GND), U2.7 (AD1), U2.8 (AD2), U2.9 (AD3), U2.11 (EP), U3.1 (GND), U3.6 (AD0), U3.8 (AD2), U3.9 (AD3), U3.11 (EP), U4.1 (GND), U5.1 (A0), U5.2 (A1), U5.3 (A2), U5.4 (GND), U6.5 (GND), U6.9 (GND), U6.10 (GND), U7.2 (GND)
unnamed: BZ1.2 (+), Q1.3 (D)
unnamed: C3.1, D1.1 (K), FB1.1, U1.3 (T+)
unnamed: C3.2, D1.2 (K), FB2.1, U1.2 (T-)
unnamed: C6.1, D2.1 (K), FB3.1, U2.3 (T+)
unnamed: C6.2, D2.2 (K), FB4.1, U2.2 (T-)
unnamed: C9.1, D3.1 (K), FB5.1, U3.3 (T+)
unnamed: C9.2, D3.2 (K), FB6.1, U3.2 (T-)
unnamed: C14.1, U6.1 (SS)
unnamed: Q2.2 (B1), Q2.5 (B2), Q2.6 (C1), R7.1
unnamed: Q2.3 (C2), Q3.1 (G), R6.1
unnamed: R4.2, SW1.2, U5.7 (WP)
unnamed: R8.1, R9.2, U6.2 (FB)

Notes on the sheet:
Hat ID EEPROM
TC 1
TC 2
TC 3
Analog Power
Board Temp
5V Switcher
Ideal Diode
Raspberry Pi Connector
Ext 1-Wire
Alert
Raspberry Pi can be safely back powered by this HAT.
Maximum Raspberry Pi current is 650mA.

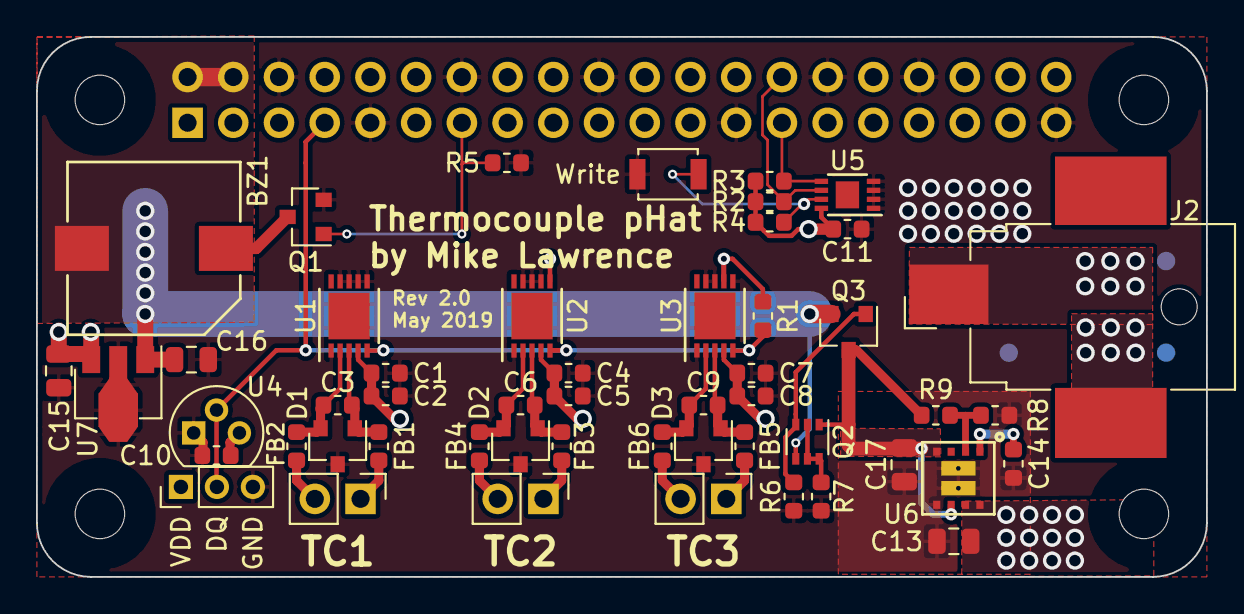
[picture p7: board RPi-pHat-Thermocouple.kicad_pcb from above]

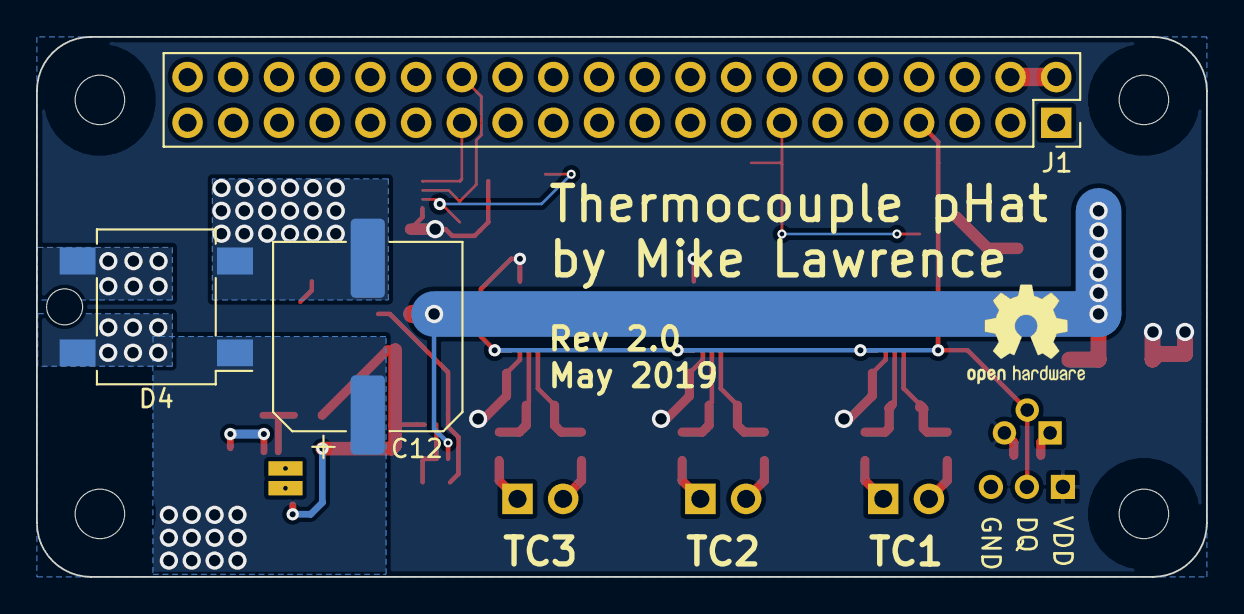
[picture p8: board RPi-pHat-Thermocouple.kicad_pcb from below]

Board: 2 copper layers, 65.0 x 30.0 mm, 54 parts (3 on the bottom side), 29 nets.

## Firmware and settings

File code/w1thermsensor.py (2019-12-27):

# -*- coding: utf-8 -*-
#
# The MIT License (MIT)
#
# Copyright (c) 2015 Timo Furrer - originally from 
# https://github.com/timofurrer/w1thermsensor/blob/master/w1thermsensor/core.py
#
# Mike Lawrence (2019) 
# added SensorFaultError, raw_max31850k_value() and get_max31850k_address()
# to better support MAX31850K devices.
# 
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
"""
    This module provides a temperature sensor of type w1 therm.
"""
import logging
import math
from os import path, listdir, system, environ
from time import sleep


class W1ThermSensorError(Exception):
    """Exception base-class for W1ThermSensor errors"""
    pass


class KernelModuleLoadError(W1ThermSensorError):
    """Exception when the w1 therm kernel modules could not be loaded"""
    def __init__(self):
        super(KernelModuleLoadError, self).__init__(
            "Cannot load w1 therm kernel modules")


class NoSensorFoundError(W1ThermSensorError):
    """Exception when no sensor is found"""
    def __init__(self, sensor_type, sensor_id):
        super(NoSensorFoundError, self).__init__("No {0} temperature sensor with id '{1}' found".format(
            W1ThermSensor.TYPE_NAMES.get(sensor_type, "Unknown"), sensor_id))


class SensorNotReadyError(W1ThermSensorError):
    """Exception when the sensor is not ready yet"""
    def __init__(self):
        super(SensorNotReadyError, self).__init__("Sensor is not yet ready to read temperature")


class UnsupportedUnitError(W1ThermSensorError):
    """Exception when unsupported unit is given"""
    def __init__(self):
        super(UnsupportedUnitError, self).__init__("Only Degrees C, F and Kelvin are currently supported")


class SensorFaultError(W1ThermSensorError):
    """Exception when sensor read resulted in a fault condition"""
    def __init__(self):
        super(SensorFaultError, self).__init__("Sensor presented a fault condition when read")


def load_kernel_modules():
    """
    Load kernel modules needed by the temperature sensor
    if they are not already loaded.
    If the base directory then does not exist an exception is raised an the kernel module loading
    should be treated as failed.

    :raises KernelModuleLoadError: if the kernel module could not be loaded properly
    """
    if not path.isdir(W1ThermSensor.BASE_DIRECTORY):
        system("modprobe w1-gpio >/dev/null 2>&1")
        system("modprobe w1-therm >/dev/null 2>&1")

    for _ in range(W1ThermSensor.RETRY_ATTEMPTS):
        if path.isdir(W1ThermSensor.BASE_DIRECTORY):  # w1 therm modules loaded correctly
            break
        sleep(W1ThermSensor.RETRY_DELAY_SECONDS)
    else:
        raise KernelModuleLoadError()


class W1ThermSensor(object):
    """This class represents a temperature sensor of type w1-therm"""
    THERM_SENSOR_DS18S20 = 0x10
    THERM_SENSOR_DS1822 = 0x22
    THERM_SENSOR_DS18B20 = 0x28
    THERM_SENSOR_DS1825 = 0x3B
    THERM_SENSOR_DS28EA00 = 0x42
    THERM_SENSOR_MAX31850K = 0x3B
    ALL_TYPES = [
        THERM_SENSOR_DS18S20, THERM_SENSOR_DS1822, THERM_SENSOR_DS18B20,
        THERM_SENSOR_DS1825, THERM_SENSOR_DS28EA00, THERM_SENSOR_MAX31850K
    ]
    DEGREES_C = 0x01
    DEGREES_F = 0x02
    KELVIN = 0x03
    BASE_DIRECTORY = "/sys/bus/w1/devices"
    SLAVE_FILE = "w1_slave"
    UNIT_FACTORS = {
        DEGREES_C: lambda x: x * 0.001,
        DEGREES_F: lambda x: x * 0.001 * 1.8 + 32.0,
        KELVIN: lambda x: x * 0.001 + 273.15
    }
    UNIT_FACTOR_NAMES = {
        "celsius": DEGREES_C,
        "fahrenheit": DEGREES_F,
        "kelvin": KELVIN
    }
    TYPE_NAMES = {
        THERM_SENSOR_DS18S20: "DS18S20", THERM_SENSOR_DS1822: "DS1822", THERM_SENSOR_DS18B20: "DS18B20",
        THERM_SENSOR_DS1825: "DS1825", THERM_SENSOR_DS28EA00: "DS28EA00", THERM_SENSOR_MAX31850K: "MAX31850K"
    }
    RESOLVE_TYPE_STR = {
        "10": THERM_SENSOR_DS18S20, "22": THERM_SENSOR_DS1822, "28": THERM_SENSOR_DS18B20,
        "42": THERM_SENSOR_DS28EA00, "3b": THERM_SENSOR_MAX31850K
    }
    RETRY_ATTEMPTS = 10
    RETRY_DELAY_SECONDS = 1.0 / float(RETRY_ATTEMPTS)

    @classmethod
    def get_available_sensors(cls, types=None):
        """
            Return all available sensors.

            :param list types: the of the sensor to look for. If types is None it will search for all available types.

            :returns: a list of sensor instances.
            :rtype: list

        """
        if not types:
            types = cls.ALL_TYPES
        is_sensor = lambda s: any(s.startswith(hex(x)[2:]) for x in types)
        return [cls(cls.RESOLVE_TYPE_STR[s[:2]], s[3:]) for s in listdir(cls.BASE_DIRECTORY) if is_sensor(s)]

    def __init__(self, sensor_type=None, sensor_id=None):
        """
            Initializes a W1ThermSensor.
            If the W1ThermSensor base directory is not found it will automatically load
            the needed kernel modules to make this directory available.
            If the expected directory will not be created after some time an exception is raised.

            If no type and no id are given the first found sensor will be taken for this instance.

            :param int sensor_type: the type of the sensor.
            :param string id: the id of the sensor.

            :raises KernelModuleLoadError: if the w1 therm kernel modules could not be loaded correctly
            :raises NoSensorFoundError: if the sensor with the given type and/or id does not exist or is not connected
        """
        self.type = sensor_type
        self.id = sensor_id
        if not sensor_type and not sensor_id:  # take first found sensor
            for _ in range(self.RETRY_ATTEMPTS):
                s = self.get_available_sensors()
                if s:
                    self.type, self.id = s[0].type, s[0].id
                    break
                sleep(self.RETRY_DELAY_SECONDS)
            else:
                raise NoSensorFoundError(None, "")
        elif not sensor_id:
            s = self.get_available_sensors([sensor_type])
            if not s:
                raise NoSensorFoundError(sensor_type, "")
            self.id = s[0].id

        # store path to sensor
        self.sensorpath = path.join(self.BASE_DIRECTORY, self.slave_prefix + self.id, self.SLAVE_FILE)

        if not self.exists():
            raise NoSensorFoundError(self.type, self.id)

    def __repr__(self):
        """
            Returns a string that eval can turn back into this object

            :returns: representation of this instance
            :rtype: string
        """
        return "{}(sensor_type={}, sensor_id='{}')".format(
            self.__class__.__name__, self.type, self.id)

    def __str__(self):
        """
            Returns a pretty string respresentation

            :returns: representation of this instance
            :rtype: string
        """
        return "{0}(name='{1}', type={2}(0x{2:x}), id='{3}')".format(
            self.__class__.__name__, self.type_name, self.type, self.id)
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

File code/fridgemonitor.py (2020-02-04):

#!/usr/bin/python3
# -*- coding: utf-8 -*-
#
# Reads temperatures from Raspberry Pi Thermocouple pHat by Mike Lawrence.
# Takes temperature averages and publishes to MQTT server.
# Supports Home Assistant MQTT Discovery directly.
#
# The MIT License (MIT)
# 
# Copyright (c) 2019 Mike Lawrence
#
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
# Can enable debug output by uncommenting:
import logging
logging.basicConfig(format='Fridge Monitor: %(message)s', level=logging.INFO)

import configparser
import datetime
import json
import math
import os
import signal
from   subprocess import PIPE, Popen
import sys
import threading
import time

import paho.mqtt.client as mqtt
import RPi.GPIO as GPIO

from w1thermsensor import W1ThermSensor
from w1thermsensor import NoSensorFoundError
from w1thermsensor import SensorNotReadyError
from w1thermsensor import SensorFaultError
from timer import InfiniteTimer
from tempdata import TempData

# User configurable values
ENABLE_AVAILABILITY_TOPIC = True
FIRMWARE = "1.0.3"
CONFFILE = "fridgemonitor.conf"
STATEFILE = "fridgemonitor.json"
ALERT = 27                      # Pin number of alert signal on PCB
SAVEFILEFREQ = 300              # how long to delay writing to state file
QOS = 1                         # MQTT Quality of Service

# Global variables
Mqttc = None
Mqttconnected = False
Lock = threading.Lock()
SaveStateTimer = None
StartTime = None
ResetAlarmDisable = True        # when True and hour is 6PM reset Alarm Disable
Hat_Product = ""


# get the Raspberry Pi CPU Serial Number
def getCpuSerial():
  # Extract serial from cpuinfo file
  cpuserial = "0000000000000000"
  try:
    f = open('/proc/cpuinfo','r')
    for line in f:
      if line[0:6]=='Serial':
        cpuserial = line[10:26]
    f.close()
  except:
    cpuserial = "00000000000Error"
  return cpuserial.strip()

def getEthMac():
  try:
    f = open('/sys/class/net/eth0/address','r')
    mac = f.readline()
    f.close()
  except:
    return None
  return mac.strip()

def getWLANMac():
  try:
    f = open('/sys/class/net/wlan0/address','r')
    mac = f.readline()
    f.close()
  except:
    return None
  return mac.strip()

class GracefulKiller:
    """Class to handle SIGTERM signal."""
    kill_now = False
    def __init__(self):
        signal.signal(signal.SIGINT, self.exit_gracefully)
        signal.signal(signal.SIGTERM, self.exit_gracefully)

    def exit_gracefully(self,signum, frame):
        self.kill_now = True

def saveStateFile():
    """Save state to file."""
    global SaveState
    with open(STATEFILE, 'w') as outfile:
        json.dump(SaveState, outfile)
    logging.info("Updated current state file %s.", STATEFILE)

def queueSaveStateFile(state):
    """Queue save state to file while preventing frequent writes to Flash."""
    global SaveState, SaveStateTimer
    # try to cancel existing timer
    try:
        SaveStateTimer.cancel()
    except:
        pass
    # keep track of state to save to file
    SaveState = state
    # delay executing save to state file function
    SaveStateTimer = threading.Timer(SAVEFILEFREQ, saveStateFile)
    SaveStateTimer.start()

def buzzer_on():
    """Turns ON alert buzzer on Thermocouple Hat."""
    GPIO.output(ALERT, GPIO.HIGH)

def buzzer_off():
    """Turns OFF alert buzzer on Thermocouple Hat."""
    GPIO.output(ALERT, GPIO.LOW)

def buzzer_beep(beeptime):
    """Turns ON alert buzzer on Hat for a period of time in seconds.
    
        :time: Time in seconds to beep (float).
    """
    GPIO.output(ALERT, GPIO.HIGH)
    time.sleep(beeptime)
    GPIO.output(ALERT, GPIO.LOW)
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

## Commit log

2017-03-17 Added .gitignore and BOM
    [RPi-pHat-Thermocouple-BOM.csv]
2017-03-17 Add Mouser BOM link
2017-03-17 Updated schematic parts fields on MAX31850k parts.
    [RPi-pHat-Thermocouple.sch]
2017-03-17 Delete RPi-pHat-Thermocouple.kicad_pcb-bak
    No reason to keep this file on GIT
2017-03-17 Added solder paste gerber for stencils.
    [RPi-pHat-Thermocouple-F.Paste.gbr]
2017-03-26 Added U2 and R5
    Fixed Alert sounding as soon as power is applied by adding pulldown
    (R5). Added Ds18S20 (U2) so the Linux kernel will properly access the
    MAX31850K.
    [RPi-pHat-Thermocouple-BOM.csv, RPi-pHat-Thermocouple.kicad_pcb, RPi-pHat-Thermocouple.sch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]
2017-03-26 Cleanup Fab layer
    [RPi-pHat-Thermocouple.kicad_pcb]
2017-04-07 Added Analog Power Supply
    [RPi-pHat-Thermocouple-BOM.csv, RPi-pHat-Thermocouple.kicad_pcb, RPi-pHat-Thermocouple.sch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]
2017-04-14 Correct Title Block Date and Revision
    [RPi-pHat-Thermocouple.sch]
2019-05-21 Remove one MAX38150K add switching power supply
    Removed one MAX38150K so now there are three on the board.
    Added switching power supply to safely backpower the Raspberry Pi Zero.
    Now has Barrel Jack for input power.
    Updated schematic BOM fields and added KiBOM support.
    [RPi-pHat-Thermocouple-BOM.csv, RPi-pHat-Thermocouple.kicad_pcb, RPi-pHat-Thermocouple.sch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]
2019-06-29 Add MQTT authentication.
    Fix configuration file defaults not working.
    PEP8 formatting.
    [fridgemonitor.py, tempdata.py]
2019-07-01 pHat is now uHat. Added check for correct Hat connected.
    [fridgemonitor.py]
2019-07-01 Reverted uHat to pHat to prevent confusion
    [fridgemonitor.py]
2019-07-02 Delete timer.cpython-37.pyc
    Remove accidental add.
2019-07-05 NIST thermocouple linearization refactor. Working good now.
    Add Enable_RSSI in config.
    Add more error checking in measureSensors().
    [fridgemonitor.py, tempdata.py, w1thermsensor.py]
2019-07-13 First operational version of Fridge Monitor.
    Thermocouple linearization now works.
    Temperature data class (tempdata) now supports 1 minute and 24 hour averaging, alarms, write/read sample data to/from files to prevent data loss on averages.
    Verifies correct Hat is connected.
    Detects door open/close with temperature only.
    [fridgemonitor.py, tempdata.py, w1thermsensor.py]
2019-12-27 Fix data file loading error when missing.
    Minor changes to README file.
    Comment out some testing code.
    [tempdata.py, w1thermsensor.py]
